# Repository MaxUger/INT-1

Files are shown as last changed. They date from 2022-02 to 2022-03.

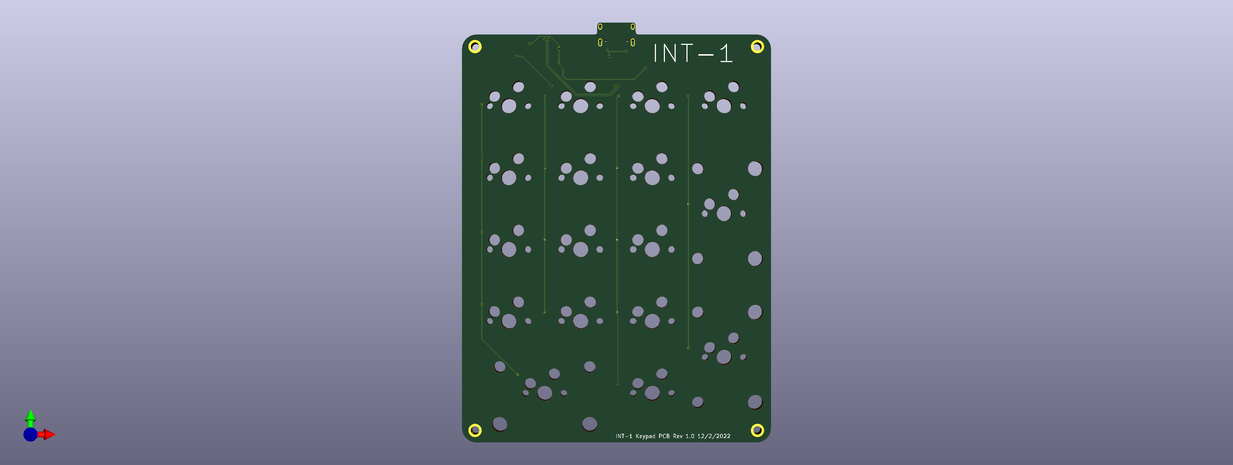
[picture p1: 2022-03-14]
Images/INT-1_Frontside.png

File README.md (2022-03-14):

# INT-1
 Mechanical Keypad.
 
 Backside:
INT-1_Backside_cropped
 Frontside:
INT-1_Frontside_cropped

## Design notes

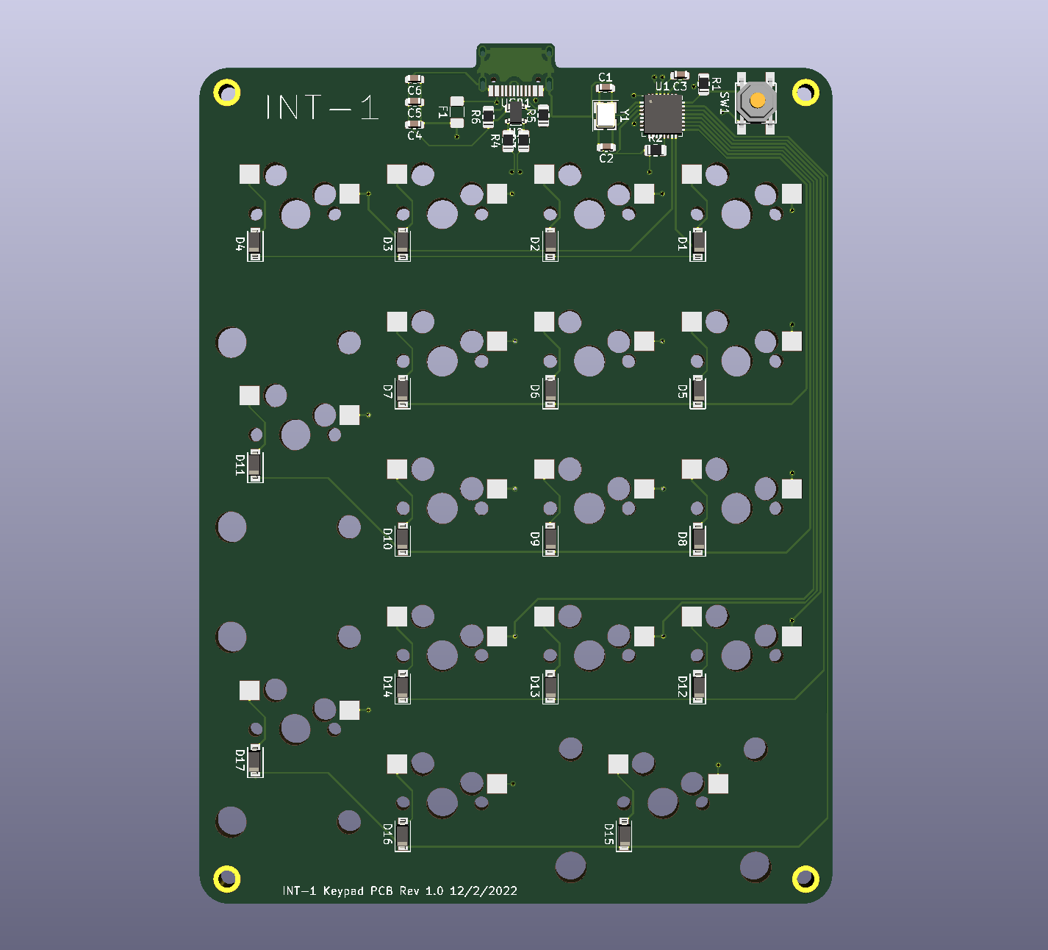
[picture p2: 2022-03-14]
Images/INT-1_Backside_cropped.png

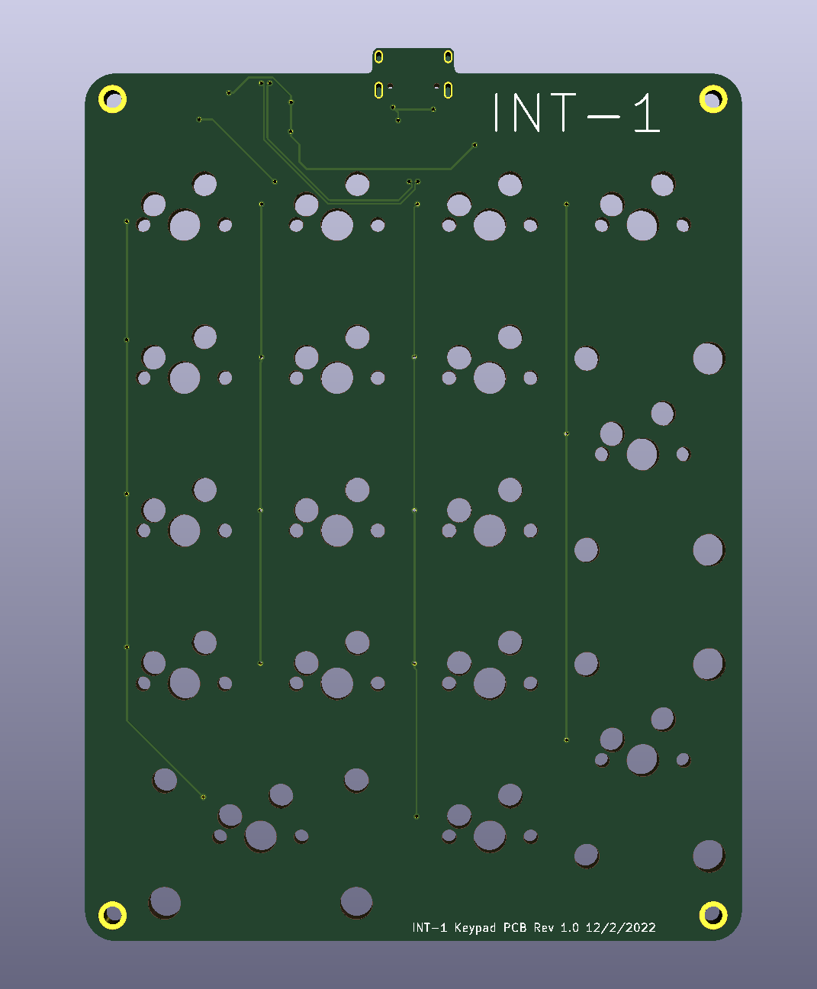
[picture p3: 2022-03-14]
Images/INT-1_Frontside_cropped.png

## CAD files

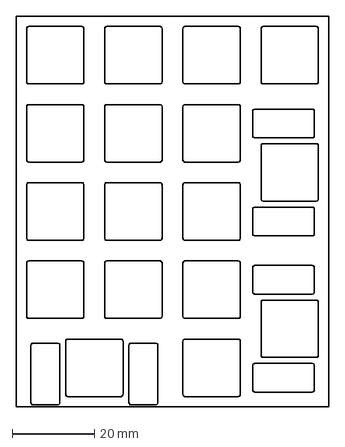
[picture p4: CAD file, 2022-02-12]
plate-2022-02-12T22 02 59.736Z.dxf
76.2 x 95.2 mm

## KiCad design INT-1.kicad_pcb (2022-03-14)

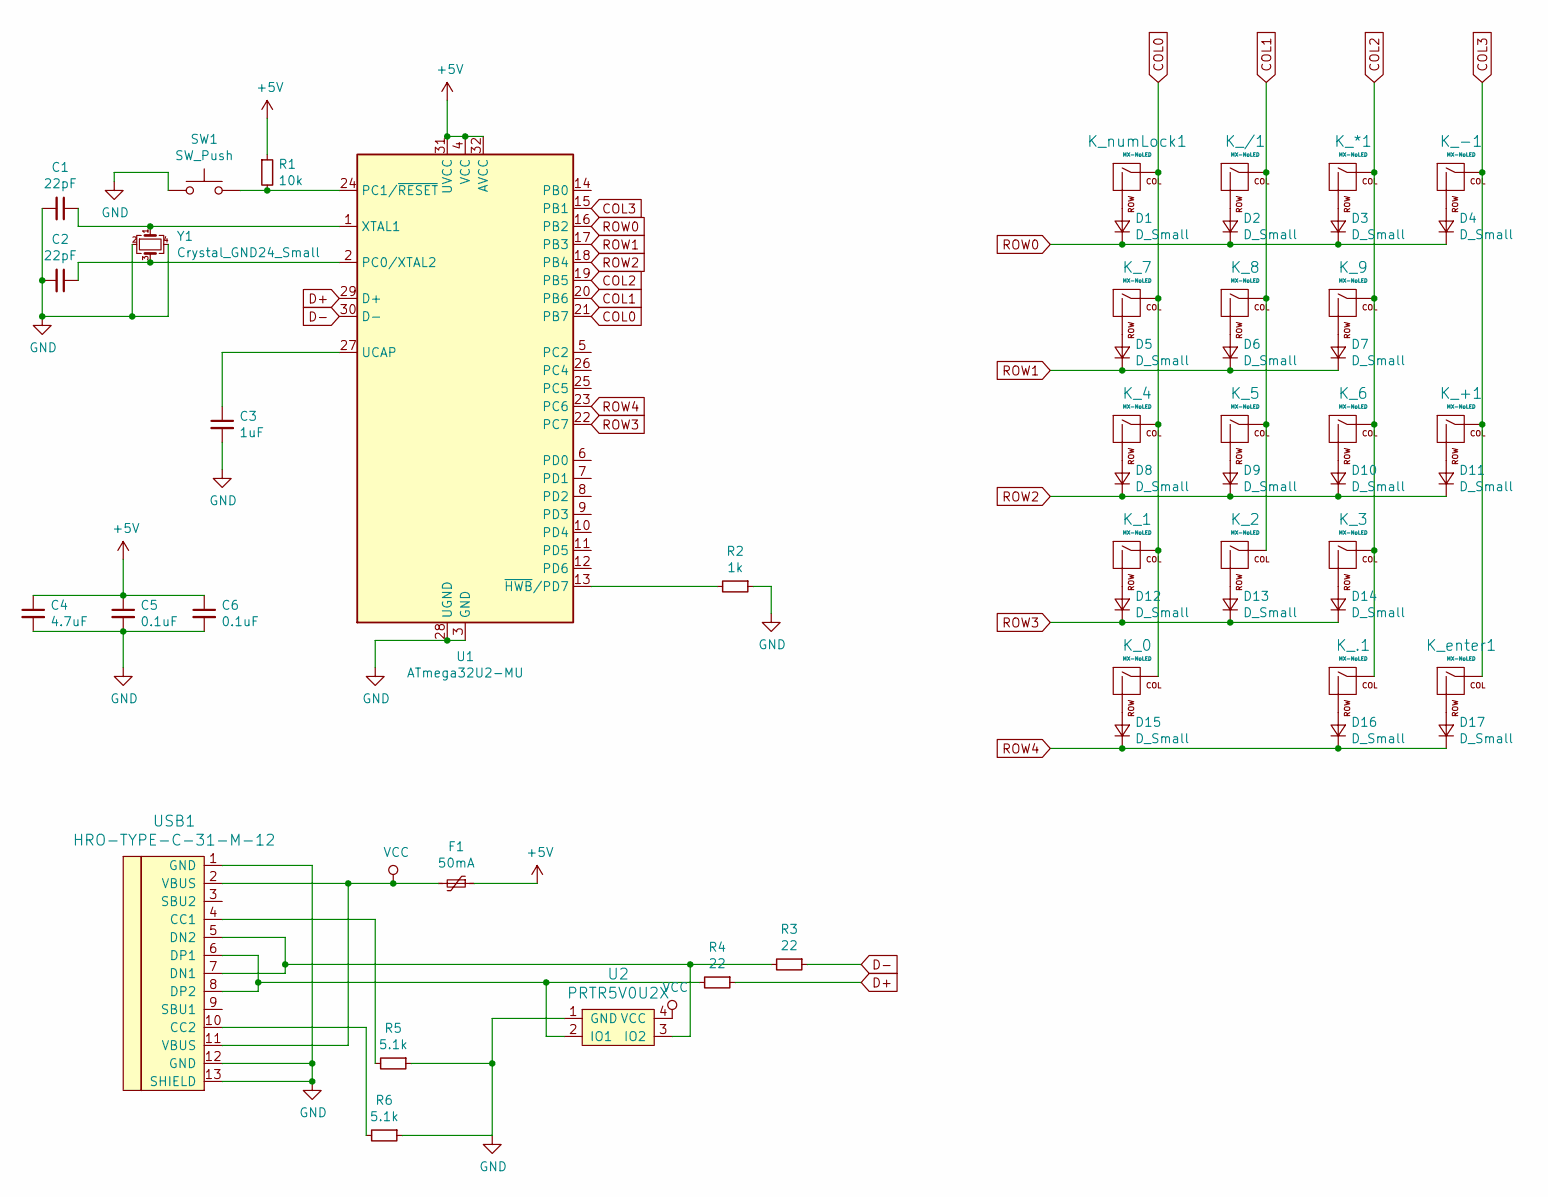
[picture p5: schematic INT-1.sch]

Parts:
C1, C2: 22pF; C_0603_1608Metric
C3: 1uF; C_0603_1608Metric
C4: 4.7uF; C_0603_1608Metric
C5, C6: 0.1uF; C_0603_1608Metric
D1, D2, D3, D4, D5, D6, D7, D8, D9, D10, D11, D12, D13, D14, D15, D16, D17: D_Small; D_SOD-123
F1: 50mA; Fuse_1206_3216Metric
K_0: MX-NoLED; MXOnly-2U-Hotswap
K_1, K_2, K_3, K_4, K_5, K_6, K_7, K_8, K_9, K_.1: MX-NoLED; MXOnly-1U-Hotswap
K_*1: MX-NoLED; MXOnly-1U-Hotswap
K_+1: MX-NoLED; MX-2U-Hotswap-Vertical
K_-1: MX-NoLED; MXOnly-1U-Hotswap
K_/1: MX-NoLED; MXOnly-1U-Hotswap
K_enter1: MX-NoLED; MX-2U-Hotswap-Vertical
K_numLock1: MX-NoLED; MXOnly-1U-Hotswap
R1: 10k; R_0805_2012Metric
R2: 1k; R_0805_2012Metric
R3, R4: 22; R_0805_2012Metric
R5, R6: 5.1k; R_0805_2012Metric
SW1: SW_Push; SKQG-1155865
U1: ATmega32U2-MU; QFN-32-1EP_5x5mm_P0.5mm_EP3.1x3.1mm
U2: PRTR5V0U2X; SOT143B
USB1: HRO-TYPE-C-31-M-12
Y1: Crystal_GND24_Small; Crystal_SMD_3225-4Pin_3.2x2.5mm

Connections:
+5V: C4.1, C5.1, C6.1, F1.1, R1.1, U1.4 (VCC), U1.31 (UVCC), U1.32 (AVCC)
COL0: K_0.1 (COL), K_1.1 (COL), K_4.1 (COL), K_7.1 (COL), K_numLock1.1 (COL), U1.21 (PB7)
COL1: K_2.1 (COL), K_5.1 (COL), K_8.1 (COL), K_/1.1 (COL), U1.20 (PB6)
COL2: K_3.1 (COL), K_6.1 (COL), K_9.1 (COL), K_*1.1 (COL), K_.1.1 (COL), U1.19 (PB5)
COL3: K_+1.1 (COL), K_-1.1 (COL), K_enter1.1 (COL), U1.15 (PB1)
D+: R4.1, U1.29 (D+)
D-: R3.1, U1.30 (D-)
GND: C1.2, C2.2, C3.2, C4.2, C5.2, C6.2, R2.1, R5.1, R6.1, SW1.1, U1.3 (GND), U1.28 (UGND), U1.33 (GND), U2.1 (GND), USB1.1 (GND), USB1.12 (GND), USB1.13 (SHIELD), Y1.2, Y1.4
unnamed: C1.1, U1.1 (XTAL1), Y1.1
unnamed: C2.1, U1.2 (PC0/XTAL2), Y1.3
unnamed: C3.1, U1.27 (UCAP)
unnamed: D1.2 (A), K_numLock1.2 (ROW)
unnamed: D2.2 (A), K_/1.2 (ROW)
unnamed: D3.2 (A), K_*1.2 (ROW)
unnamed: D4.2 (A), K_-1.2 (ROW)
unnamed: D5.2 (A), K_7.2 (ROW)
unnamed: D6.2 (A), K_8.2 (ROW)
unnamed: D7.2 (A), K_9.2 (ROW)
unnamed: D8.2 (A), K_4.2 (ROW)
unnamed: D9.2 (A), K_5.2 (ROW)
unnamed: D10.2 (A), K_6.2 (ROW)
unnamed: D11.2 (A), K_+1.2 (ROW)
unnamed: D12.2 (A), K_1.2 (ROW)
unnamed: D13.2 (A), K_2.2 (ROW)
unnamed: D14.2 (A), K_3.2 (ROW)
unnamed: D15.2 (A), K_0.2 (ROW)
unnamed: D16.2 (A), K_.1.2 (ROW)
unnamed: D17.2 (A), K_enter1.2 (ROW)
unnamed: R1.2, SW1.2, U1.24 (PC1/~RESET)
unnamed: R2.2, U1.13 (~HWB~/PD7)
unnamed: R3.2, U2.3 (IO2), USB1.5 (DN2), USB1.7 (DN1)
unnamed: R4.2, U2.2 (IO1), USB1.6 (DP1), USB1.8 (DP2)
unnamed: R5.2, USB1.4 (CC1)
unnamed: R6.2, USB1.10 (CC2)
ROW0: D1.1 (K), D2.1 (K), D3.1 (K), D4.1 (K), U1.16 (PB2)
ROW1: D5.1 (K), D6.1 (K), D7.1 (K), U1.17 (PB3)
ROW2: D8.1 (K), D9.1 (K), D10.1 (K), D11.1 (K), U1.18 (PB4)
ROW3: D12.1 (K), D13.1 (K), D14.1 (K), U1.22 (PC7)
ROW4: D15.1 (K), D16.1 (K), D17.1 (K), U1.23 (PC6)
VCC: F1.2, U2.4 (VCC), USB1.2 (VBUS), USB1.11 (VBUS)

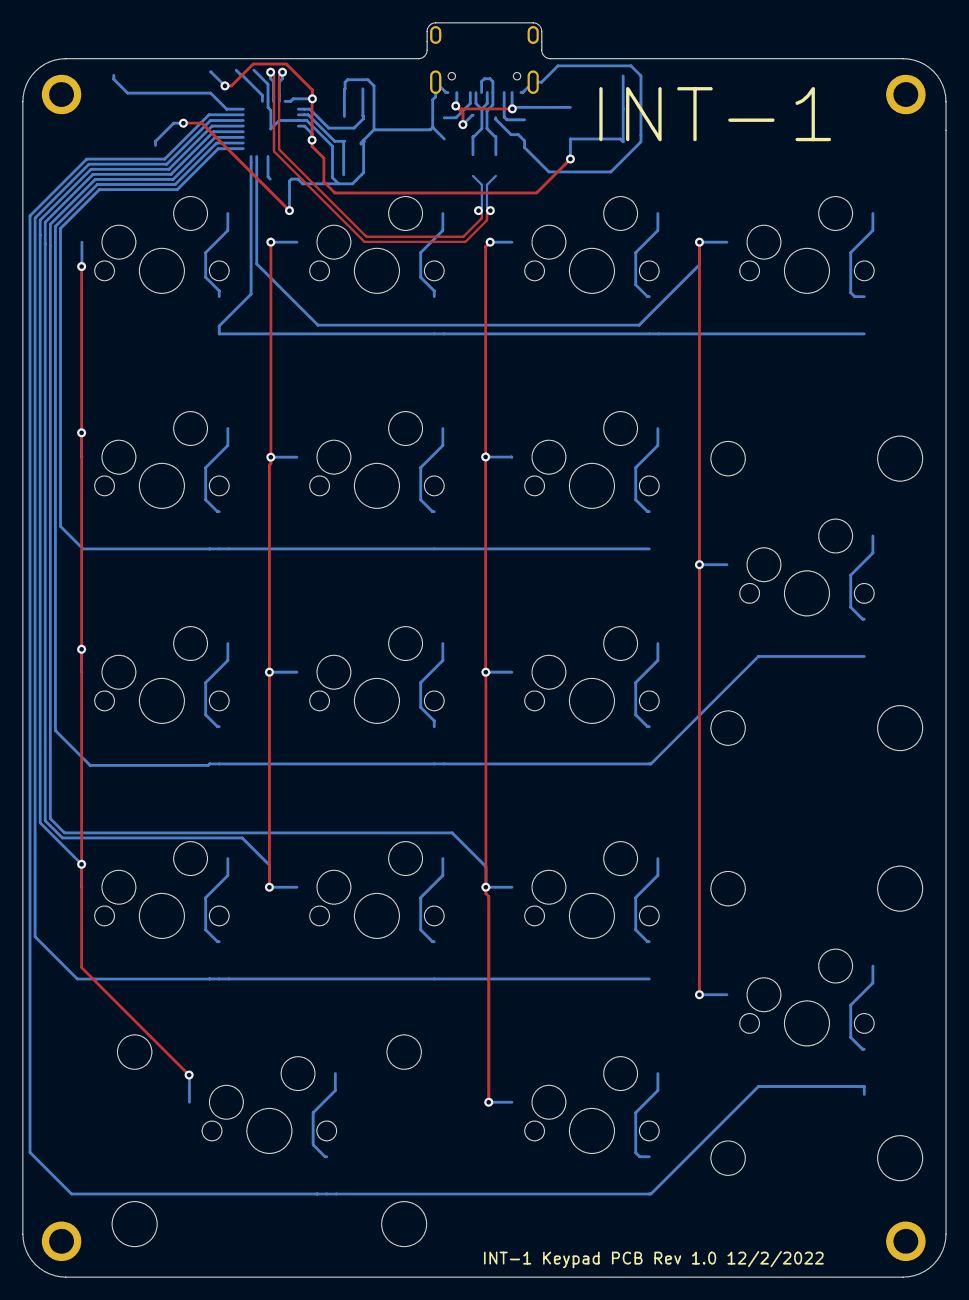
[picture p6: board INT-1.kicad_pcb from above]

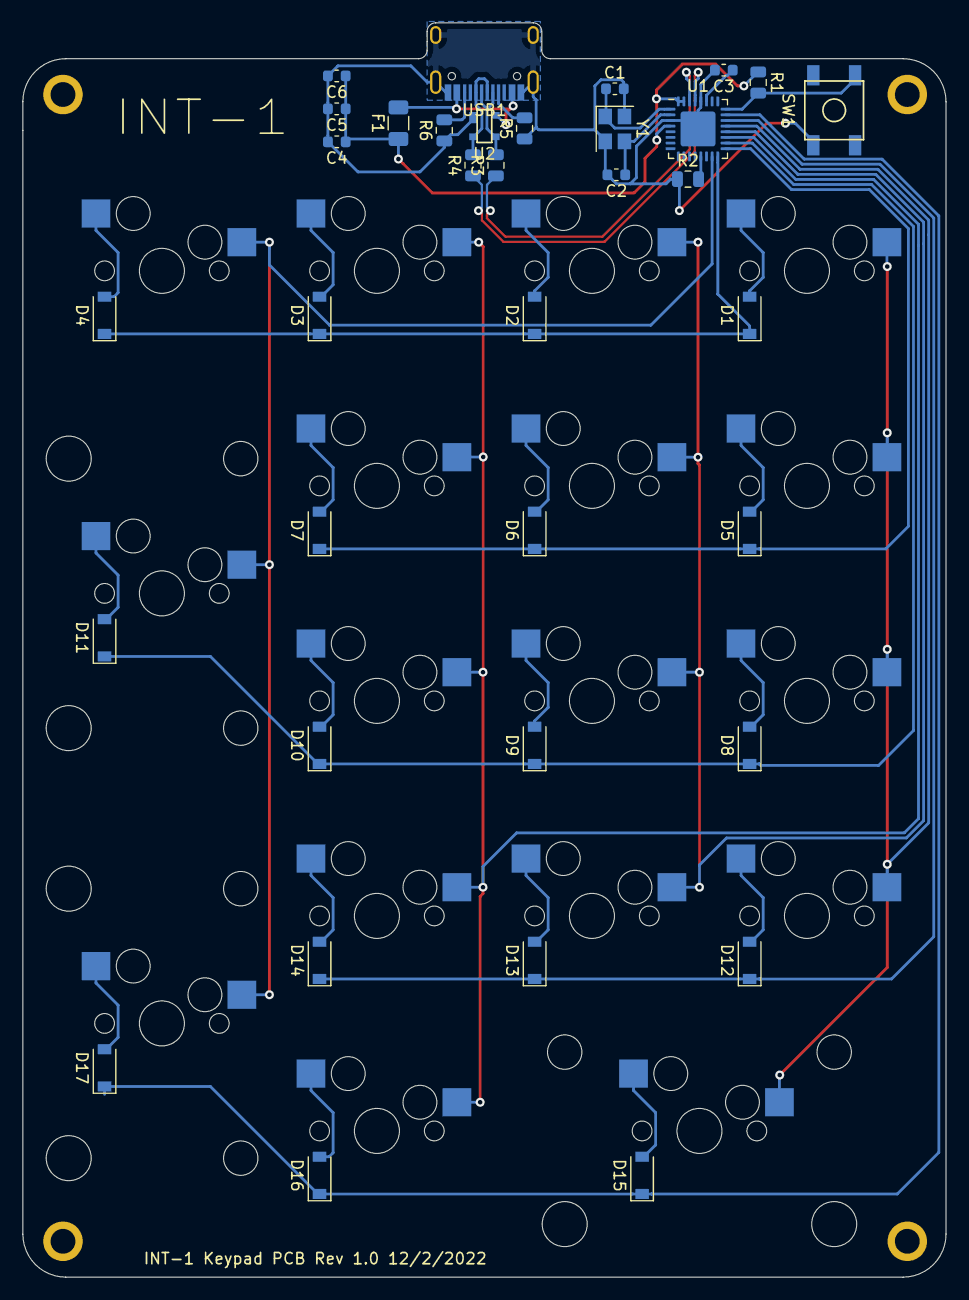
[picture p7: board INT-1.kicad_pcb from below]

Board: 2 copper layers, 81.8 x 111.1 mm, 52 parts (35 on the bottom side), 40 nets.

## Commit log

2022-02-08 Added Submodules
    [INT-1.kicad_pcb, INT-1.sch]
2022-02-09 Finished Schematic
2022-02-11 Assigned Footprints
    [INT-1.sch]
2022-02-12 Finished diode placement
    [INT-1.sch, plate-2022-02-12T22 02 59.736Z.dxf]
2022-02-12 Finished edge cuts
    [INT-1.kicad_pcb]
2022-02-13 Finished trace routing
    [INT-1.kicad_pcb, INT-1.sch]
2022-02-13 Added mounting holes
    [INT-1.kicad_pcb]
2022-02-13 Added Text
    [INT-1.kicad_pcb]
2022-02-14 Generated gerbers
    [INT-1-B_Cu.gbr, INT-1-B_Mask.gbr, INT-1-B_Paste.gbr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]
2022-03-14 Added 3d models
    [INT-1.kicad_pcb]
